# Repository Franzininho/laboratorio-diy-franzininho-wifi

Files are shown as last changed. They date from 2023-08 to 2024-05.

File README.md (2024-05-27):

## Laboratório DIY - Franzininho Wifi

Gif da placa

## O que é este projeto?

O projeto **Laboratório DIY - Franzininho Wifi** é um projeto de placa de circuito impresso para facilitar o uso de componentes eletrônicos em oficinas de programação. Este projeto possui um socket para conexão da placa [Franzininho Wifi](https://github.com/Franzininho/Franzininho-WiFi) e diversos periféricos conectados à pinos pré-determinados do socket que podem ser ativados utilizando um conector jumper ou mais.

Esse projeto tem o intuito de auxiliar no ensino de programação utilizando a placa Franzininho Wifi já que muitas vezes nas oficinas de programação com placas microcontroladas é despendido muito tempo para lidar com problemas que vem da manipulação do hardware como utilização da protoabord e realização de conexões. Este tempo muitas vezes acaba prejudicando a atividade já que o tempo onde se foca em fazer as conexões eletrônicas poderia ser melhor aproveitado focando na programação realmente.

Sendo assim, utilizando a facilidade de conexão de periféridos da placa é possível reduzir drásticamente o tempo despendido para conexões eletrônicas, focando no objetivo da oficina, que é a programação.

Esse projeto está sob a licença [CERN-OHL-S v2](https://ohwr.org/cern_ohl_s_v2.txt)

## Como ativar os periféricos?

Os periféricos utilizados na placa são ativados através de pinos de ativação. Esses pinos são compostos por dois pinos macho que devem ser conectados. Um desses pinos macho está conectado ao socket da placa e o outro a um pino do componente eletrônico. Dessa forma, o jumper fecha a conexão entre o componente e a placa microcontrolada.

Como "ativador" para os pinos, recomendo o uso do conector da imagem abaixo. Você pode encontrar esse conector como "jumper com aba", "mini jumper com aba", "jumper cap", entre outros.

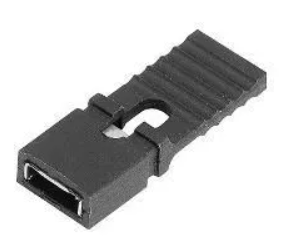
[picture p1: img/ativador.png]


Além dos pinos de ativação de sinal que conectam o componente ao socket da placa, existem também os pinos de ativação de energia que são responsáveis por energizar o componente.

## Codificação dos pinos de ativação

Devido à quantidade de pinos de ativação usada na placa, foi preciso desenvolver um sistema de codificação para esses pinos. Esse sistema foi idealizado com cada pino sendo representado por dois algorismos. O primeiro indicando a funcionalidade do pino e o segundo indicando uma numeração do pino. Esse sistema foi utilizado para todos os pinos com exceção dos pinos SDA e SCK. As funções dos primeiros algorismos podem ser vistas abaixo:

| Letra | Significado |
| :---: | :---: |
| L | LED |
| P | Piezo Buzzer |
| B | Botões |
| M | Servo Motor |
| S | Sensores |
|  SDA  | SDA |
|  SCK  | SCK |
| E | Conexões externas |
| 3 | VCC 3.3V |
| 5 | VCC 5V |

O código correspondente a cada pino de ativação foi impresso ao lado desse pino e o mapeamento dos pinos de ativação para os pinos da placa Franzininho Wifi está impresso na placa e também pode ser acessado [clicando aqui](./mapeamento.md). Além disso, também foi desenvolvida uma biblioteca para uso em conjunto com a placa que permite o uso dos códigos dos pinos de ativação dentro da programação. [Clique aqui para acessar a **biblioteca laboratorioFW-DIY**](https://github.com/Franzininho/biblioteca-laboratorioFW-DIY)

## Como o projeto foi desenvolvido?

O projeto foi desenvolvido com o software [KiCad 7](https://www.kicad.org/). Esse software é aberto e está disponível para Linux, MacOS e Windows.

#### Feito por [LelePG](https://github.com/LelePG)

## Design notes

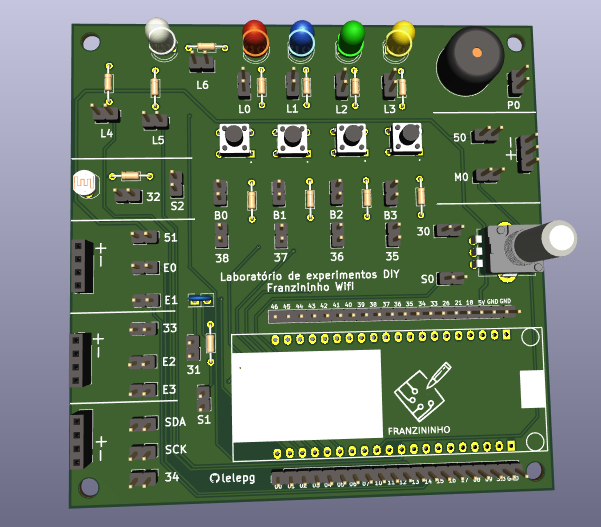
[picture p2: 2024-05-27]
img/top.png

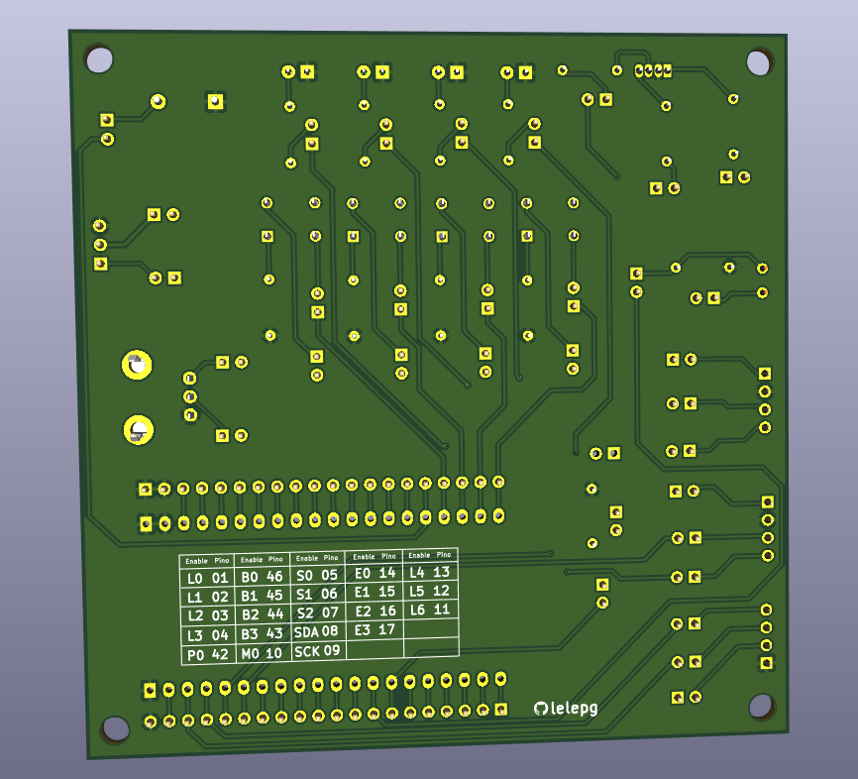
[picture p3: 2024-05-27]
img/bottom.png

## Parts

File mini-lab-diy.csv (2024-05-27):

Id | Designator | Footprint | Quantity | Designation | Supplier and ref
1 | R3,R7,R10,R5,R6,R8,R11,R1,R4,R9,R2 | R_Axial_DIN0204_L3.6mm_D1.6mm_P7.62mm_Horizontal | 11 | 150Ω
2 | Enable34,Enable51,EnableB3,EnableE2,Enable50,EnableE1,EnableL2,Enable30,EnableP0,Enable37,EnableM0,Enable33,EnableS1,Enable36,EnableB1,EnableL5,EnableE3,EnableS0,Enable38,EnableS2,Enable35,EnableL3,EnableB0,EnableE0,Enable31,EnableB2,EnableL4,EnableSCK0,Enable32,Enable1,EnableL6,Enable0,EnableSDA0,EnableL1,EnableL0 | PinHeader_1x02_P2.54mm_Vertical | 35 | Conn_01x02
3 | D1 | LED_D5.0mm | 1 | LED1
4 | SW1,SW4,SW2,SW3 | Switch | 4 | SW_Push_Dual
5 | D2 | LED_D5.0mm | 1 | LED2
6 | R13,R12 | R_Axial_DIN0204_L3.6mm_D1.6mm_P7.62mm_Horizontal | 2 | 10KΩ
7 | TH1 | PinHeader_2x01_P2.54mm_Vertical | 1 | Thermistor_NTC
8 | U3 | FRANZININHO_WIFI_PINOUT | 1 | FRANZININHO_WIFI_PINOUT
9 | LDR1 | R_LDR_5.1x4.3mm_P3.4mm_Vertical | 1 | LDR07
10 | POT1 | Potentiometer_Alpha_RD901F-40-00D_Single_Vertical_CircularHoles | 1 | 1KΩ
11 | D4 | LED_D5.0mm | 1 | LED4
12 | I2C,Jumpers1,Jumpers2 | PinHeader_1x04_P2.54mm_Vertical | 3 | Conn_01x04
13 | J2,J1 | PinHeader_1x20_P2.54mm_Vertical | 2 | Conn_01x20
14 | M1 | PinHeader_1x03_P2.54mm_Vertical | 1 | Motor_Servo
15 | Buzzer1 | Buzzer_12x9.5RM7.6 | 1 | Speaker
16 | LED5 | LED_D5.0mm-4_RGB | 1 | LED_RGBA
17 | D3 | LED_D5.0mm | 1 | LED3

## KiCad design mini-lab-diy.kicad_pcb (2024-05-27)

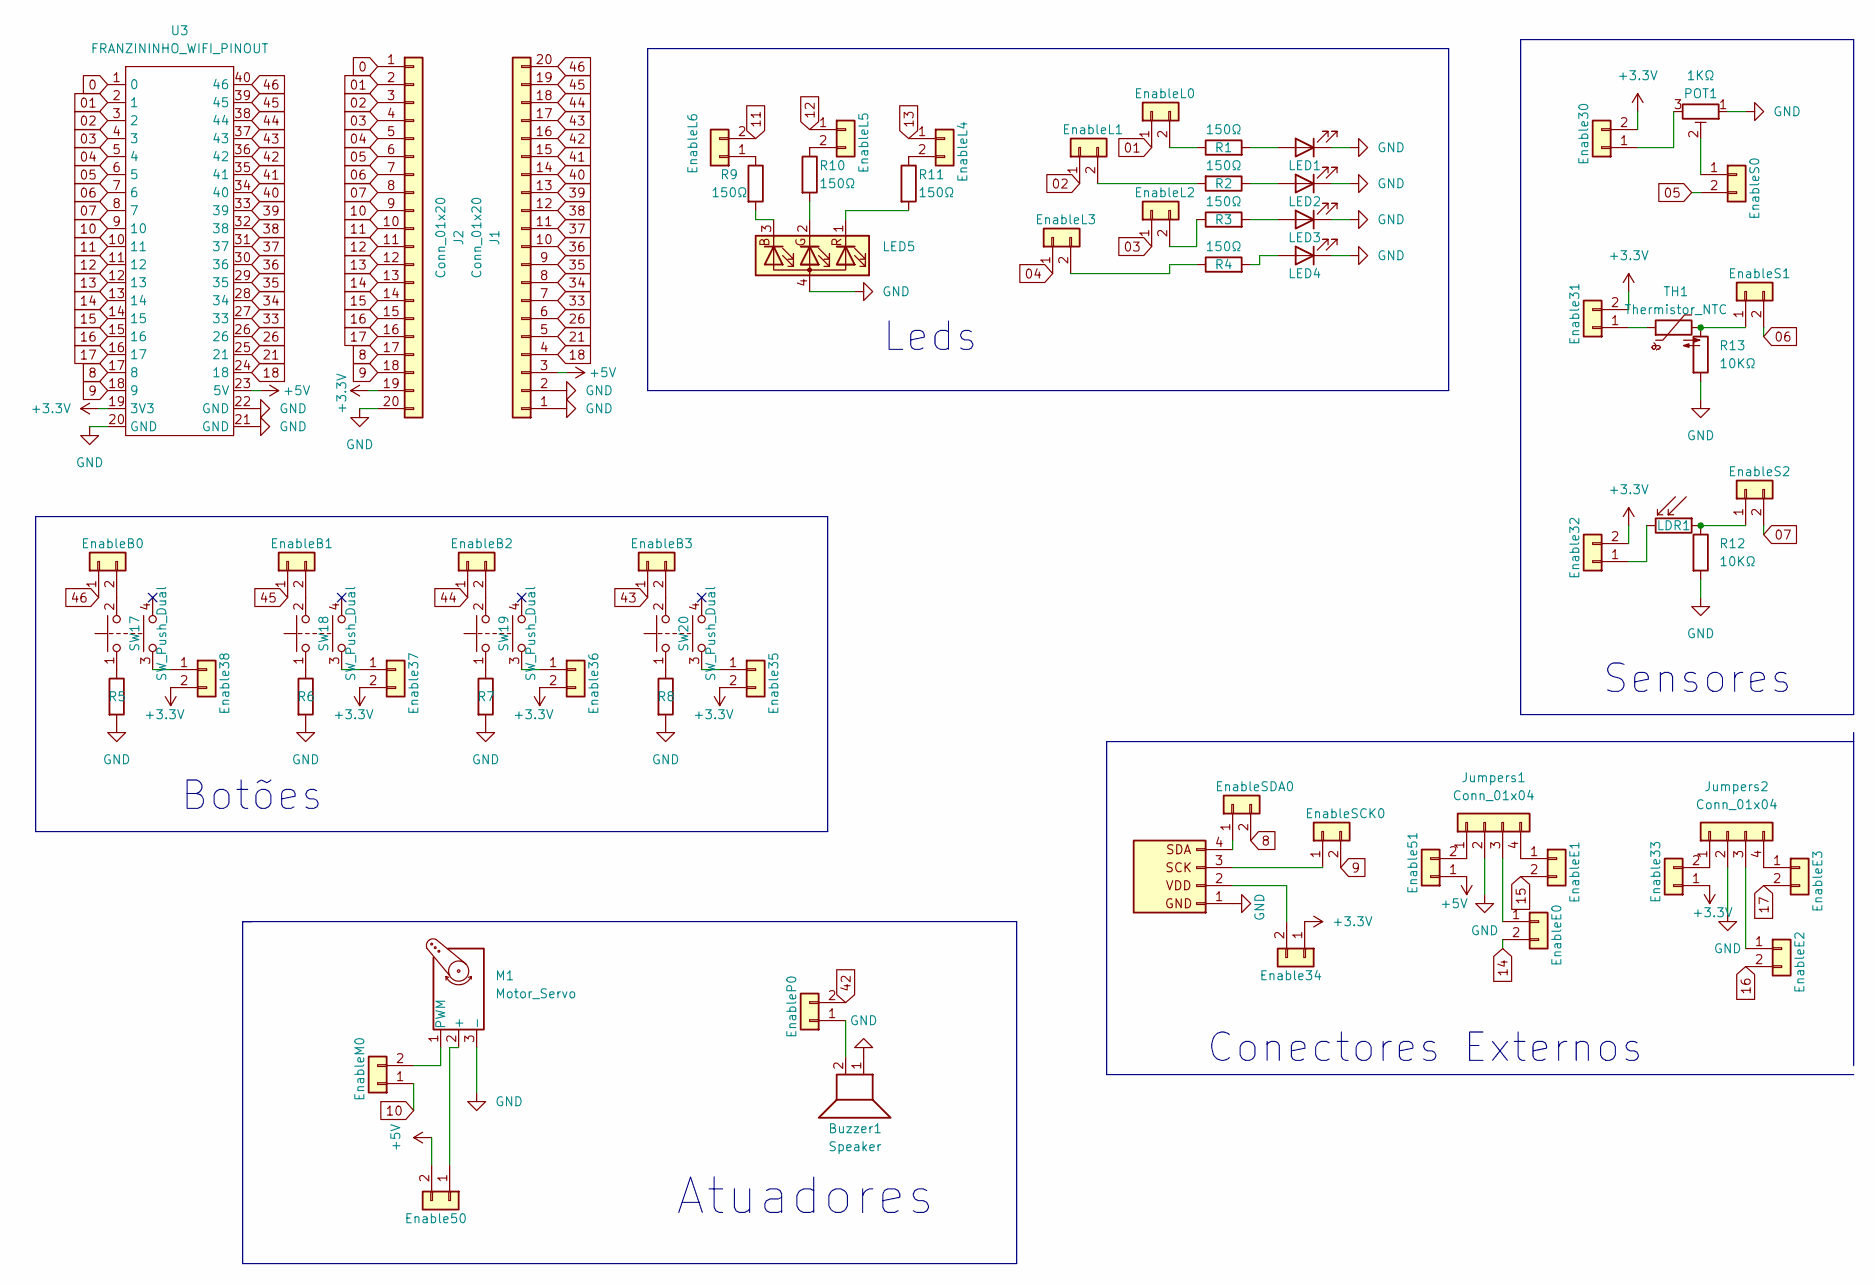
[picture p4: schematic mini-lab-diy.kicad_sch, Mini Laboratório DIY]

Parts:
Buzzer1: Speaker; Buzzer_12x9.5RM7.6
D1: LED1; LED_D5.0mm
D2: LED2; LED_D5.0mm
D3: LED3; LED_D5.0mm
D4: LED4; LED_D5.0mm
Enable30, Enable31, Enable32, Enable33, Enable34, Enable35, Enable36, Enable37, Enable38, Enable50, Enable51: Conn_01x02; PinHeader_1x02_P2.54mm_Vertical
EnableB0, EnableB1, EnableB2, EnableB3: Conn_01x02; PinHeader_1x02_P2.54mm_Vertical
EnableE0, EnableE1, EnableE2, EnableE3: Conn_01x02; PinHeader_1x02_P2.54mm_Vertical
EnableL0, EnableL1, EnableL2, EnableL3, EnableL4, EnableL5, EnableL6: Conn_01x02; PinHeader_1x02_P2.54mm_Vertical
EnableM0: Conn_01x02; PinHeader_1x02_P2.54mm_Vertical
EnableP0: Conn_01x02; PinHeader_1x02_P2.54mm_Vertical
EnableS0, EnableS1, EnableS2: Conn_01x02; PinHeader_1x02_P2.54mm_Vertical
EnableSCK0: Conn_01x02; PinHeader_1x02_P2.54mm_Vertical
EnableSDA0: Conn_01x02; PinHeader_1x02_P2.54mm_Vertical
J1, J2: Conn_01x20; PinHeader_1x20_P2.54mm_Vertical
Jumpers1, Jumpers2: Conn_01x04; PinHeader_1x04_P2.54mm_Vertical
LDR1: LDR07; R_LDR_5.1x4.3mm_P3.4mm_Vertical
LED5: LED_RGBA; LED_D5.0mm-4_RGB
M1: Motor_Servo; PinHeader_1x03_P2.54mm_Vertical
POT1: 1KΩ; Potentiometer_Bourns_PTV09A-1_Single_Vertical
R1, R2, R3, R4, R5, R6, R7, R8, R9, R10, R11: 150Ω; R_Axial_DIN0204_L3.6mm_D1.6mm_P7.62mm_Horizontal
R12, R13: 10KΩ; R_Axial_DIN0204_L3.6mm_D1.6mm_P7.62mm_Horizontal
SW17, SW18, SW19, SW20: SW_Push_Dual; Switch
TH1: Thermistor_NTC; PinHeader_2x01_P2.54mm_Vertical
Tela1: Conn_01x04; PinHeader_1x04_P2.54mm_Vertical
U3: FRANZININHO_WIFI_PINOUT

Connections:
0: J2.1, U3.1 (0)
01: EnableL0.1, J2.2, U3.2 (1)
02: EnableL1.1, J2.3, U3.3 (2)
03: EnableL2.1, J2.4, U3.4 (3)
04: EnableL3.1, J2.5, U3.5 (4)
05: EnableS0.2, J2.6, U3.6 (5)
06: EnableS1.2, J2.7, U3.7 (6)
07: EnableS2.2, J2.8, U3.8 (7)
8: EnableSDA0.2, J2.17, U3.17 (8)
9: EnableSCK0.2, J2.18, U3.18 (9)
10: EnableM0.1, J2.9, U3.9 (10)
11: EnableL6.2, J2.10, U3.10 (11)
12: EnableL5.1, J2.11, U3.11 (12)
13: EnableL4.1, J2.12, U3.12 (13)
14: EnableE0.2, J2.13, U3.13 (14)
15: EnableE1.2, J2.14, U3.14 (15)
16: EnableE2.2, J2.15, U3.15 (16)
17: EnableE3.2, J2.16, U3.16 (17)
18: J1.4, U3.24 (18)
21: J1.5, U3.25 (21)
26: J1.6, U3.26
33: J1.7, U3.27 (33)
34: J1.8, U3.28 (34)
35: J1.9, U3.29 (35)
36: J1.10, U3.30 (36)
37: J1.11, U3.31 (37)
38: J1.12, U3.32 (38)
39: J1.13, U3.33 (39)
40: J1.14, U3.34 (40)
41: J1.15, U3.35 (41)
42: EnableP0.2, J1.16, U3.36 (42)
43: EnableB3.1, J1.17, U3.37 (43)
44: EnableB2.1, J1.18, U3.38 (44)
45: EnableB1.1, J1.19, U3.39 (45)
46: EnableB0.1, J1.20, U3.40 (46)
+3.3V: Enable30.2, Enable31.2, Enable32.2, Enable33.1, Enable34.1, Enable35.2, Enable36.2, Enable37.2, Enable38.2, J2.19, U3.19 (3V3)
+5V: Enable50.2, Enable51.1, J1.3, U3.23 (5V)
GND: Buzzer1.1, D1.1 (K), D2.1 (K), D3.1 (K), D4.1 (K), J1.1, J1.2, J2.20, Jumpers1.2, Jumpers2.2, LED5.4 (A), M1.3 (-), POT1.1, R5.2, R6.2, R7.2, R8.2, R12.2, R13.2, Tela1.1, U3.20 (GND), U3.21 (GND), U3.22 (GND)
unnamed: D1.2 (A), R1.2
unnamed: D2.2 (A), R2.1
unnamed: D3.2 (A), R3.2
unnamed: D4.2 (A), R4.2
unnamed: Enable30.1, POT1.3
unnamed: Enable31.1, TH1.1
unnamed: Enable32.1, LDR1.2
unnamed: Enable33.2, Jumpers2.1
unnamed: Enable34.2, Tela1.2
unnamed: Enable35.1, SW20.3
unnamed: Enable36.1, SW19.3
unnamed: Enable37.1, SW18.3
unnamed: Enable38.1, SW17.3
unnamed: Enable50.1, M1.2 (+)
unnamed: Enable51.2, Jumpers1.1
unnamed: EnableB0.2, SW17.2
unnamed: EnableB1.2, SW18.2
unnamed: EnableB2.2, SW19.2
unnamed: EnableB3.2, SW20.2
unnamed: EnableE0.1, Jumpers1.3
unnamed: EnableE1.1, Jumpers1.4
unnamed: EnableE2.1, Jumpers2.3
unnamed: EnableE3.1, Jumpers2.4
unnamed: EnableL0.2, R1.1
unnamed: EnableL1.2, R2.2
unnamed: EnableL2.2, R3.1
unnamed: EnableL3.2, R4.1
unnamed: EnableL4.2, R11.1
unnamed: EnableL5.2, R10.1
unnamed: EnableL6.1, R9.1
unnamed: EnableM0.2, M1.1 (PWM)
unnamed: Buzzer1.2, EnableP0.1
unnamed: EnableS0.1, POT1.2
unnamed: EnableS1.1, R13.1, TH1.2
unnamed: EnableS2.1, LDR1.1, R12.1
unnamed: EnableSCK0.1, Tela1.3
unnamed: EnableSDA0.1, Tela1.4
unnamed: LED5.3 (BK), R9.2
unnamed: LED5.2 (GK), R10.2
unnamed: LED5.1 (RK), R11.2
unnamed: R5.1, SW17.1
unnamed: R6.1, SW18.1
unnamed: R7.1, SW19.1
unnamed: R8.1, SW20.1

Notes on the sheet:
Leds
Conectores Externos
Botões
Atuadores
Sensores

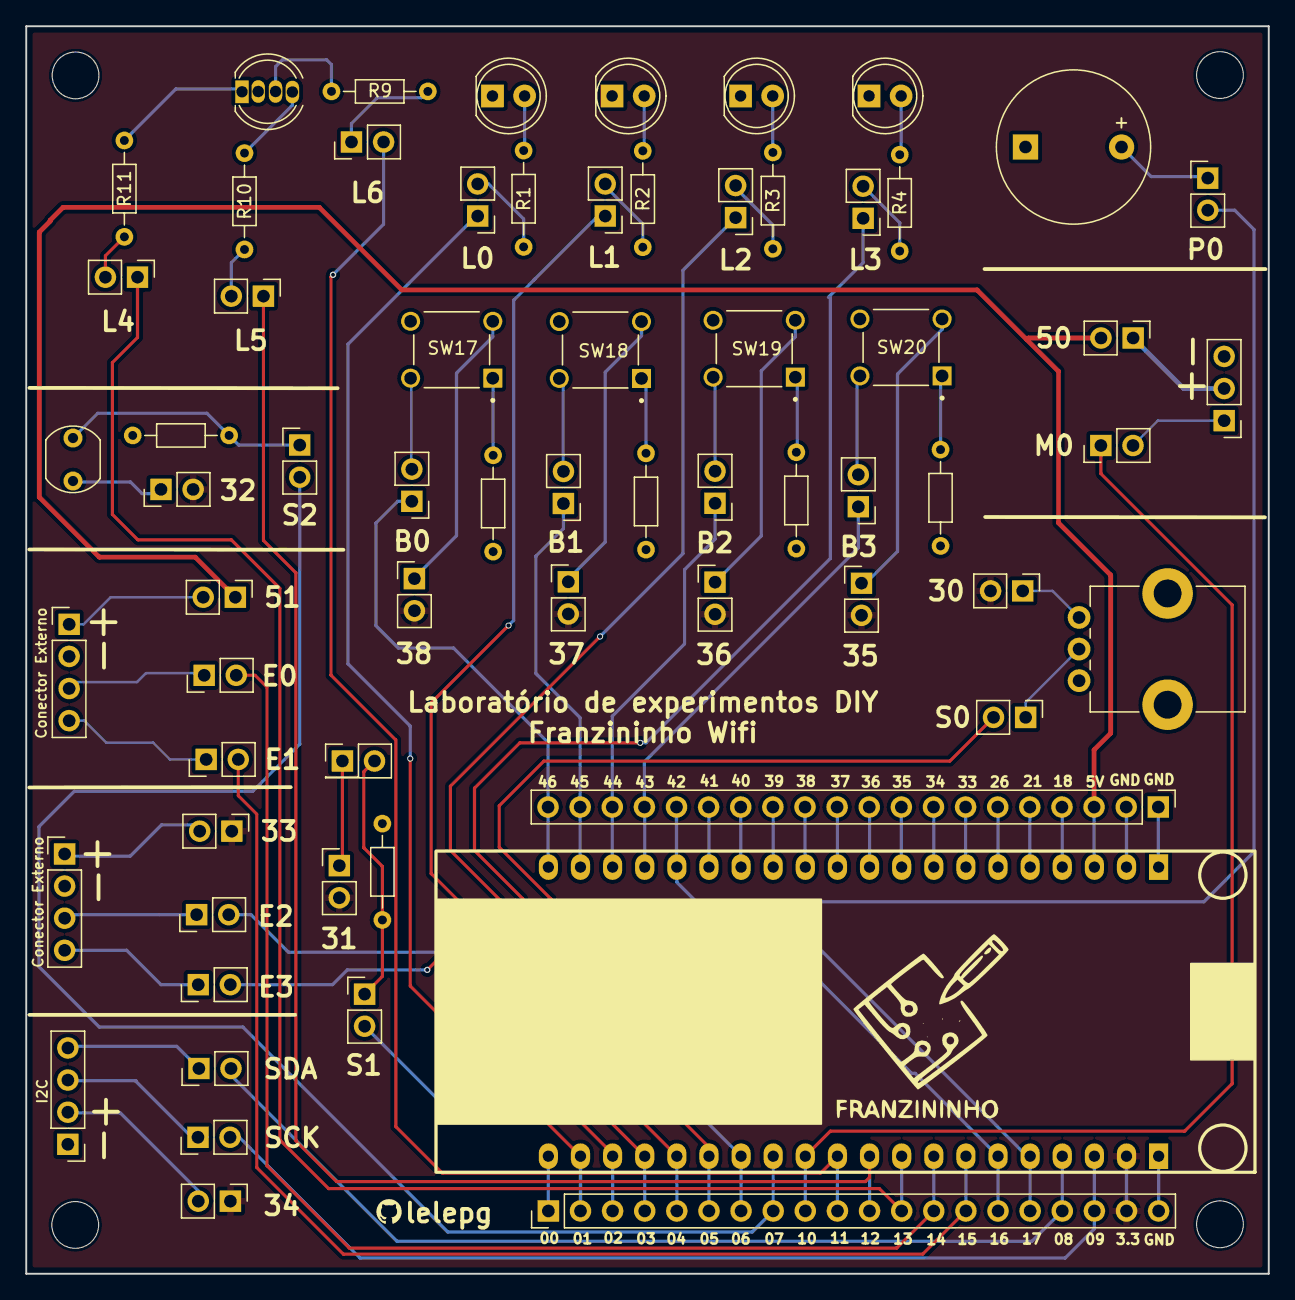
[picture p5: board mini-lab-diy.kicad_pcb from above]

Board: 2 copper layers, 98.3 x 98.7 mm, 66 parts (0 on the bottom side), 82 nets.

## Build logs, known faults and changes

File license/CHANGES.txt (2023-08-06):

Change Format
Your name Date Description of modification

Change Log

Letícia Garcez 2023-08-06 Initial release of Laboratório DIY - Franzininho Wifi under cern_ohl_s_v2

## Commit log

2023-08-06 commit inicial
    [mini-lab-diy.kicad_pcb, mini-lab-diy.kicad_sch]
2024-01-08 modificação de orientação de alguns pads
    [mini-lab-diy.kicad_pcb]
2024-05-27 retirada dos gnd do led rgb e do motor, e aumento no espaçamento dos dados da silk
    [mini-lab-diy.csv, mini-lab-diy.kicad_pcb, mini-lab-diy.kicad_sch]
